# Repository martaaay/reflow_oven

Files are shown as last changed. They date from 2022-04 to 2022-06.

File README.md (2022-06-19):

# Reflow Oven

Based on EZ Make Oven by Adafruit.

* Sparkfun MCP9600 with QWIIC connectors
* Hamilton Beach Countertop Toaster Oven & Pizza Maker 31401
* Adafruit Metro M4 feat. Microchip ATSAMD51
* Adafruit "Music Maker" MP3 Shield for Arduino w/3W Stereo Amp
* Speaker - 40mm Diameter - 4 Ohm 3 Watt
* 2.8" TFT Touch Shield for Arduino w/Capacitive Touch
* SSR-25DA DC->AC. https://www.amazon.com/gp/product/B08GPJ1V2J 

The toaster oven should disassembled and insulated. This is a good guide:
https://www.whizoo.com/reflowoven
Don't skimp on the reflective tape on the door! Be careful about wiring as 110V is involved.

Pry the knobs off the front panel. I suggest using a regular screwdriver from the back and twisting
to pry it up. Once off, unscrew all the controls so you're left with the bent sheetmetal. Print
the front panel in a higher temp plastic (though it really wont have to handle much heat). I printed
in Nylon. ABS should work too. Using a dremal + grinder (or something similar) carefully cutout a rectangle
to fit the front panel. Insert threaded inserts into the screw holes in the front panel. These work great:
https://www.amazon.com/gp/product/B07LBRR2ZB/
And screw it into place in the sheet metal front panel. The rest is just wiring, testing, and re-assembling.

Future work:
* Consider swapping to Arduino code over Circuit Python. Circuit Python is very slow, especially for playing
sounds.

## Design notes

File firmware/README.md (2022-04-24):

# EZ Make Oven

The EZ Make Oven is an easy to build reflow oven utilizing a PyPortal as
the controller. It also uses the Adafruit MCP9600 thermocouple amplifier, a thermocouple and the IoT Power Relay from Digital Loggers.

A standard, non-digital toaster oven is needed for this project, which can be purchased online or at your nearest appliance store. It should be small (4 slice capacity), at least 1100 watts and a maximum temperature of 450F / 230C or better.

Follow the Adafruit learn guide here: https://learn.adafruit.com/ez-make-oven

Run **codecalibrate.py** first to determine calibration settings for your toaster oven. You will need to re-run this if you switch toaster ovens or update the EZ Make Oven software. The calibration values displayed will need to be manually entered into the **config.json file**. This file also contains the I2C address of your MCP9600 breakout (in decimal) and the name of the solder profile to use. Available solder profiles can be found in the profiles folder. You will need to rename this file to **code.py** in order to run it.

**code.py** is the EZ Make Oven code that will run the program when the board boots up.

Adafruit invests time and resources providing this open source code,
please support Adafruit and open-source hardware by purchasing
products from [Adafruit](https://www.adafruit.com)!
 
MIT license, code and guide written by Dan Cogliano

All text above, and the splash screen below must be included in any redistribution

-----------------------
If you are looking to make changes/additions, please use the GitHub Issues and Pull Request mechanisms.

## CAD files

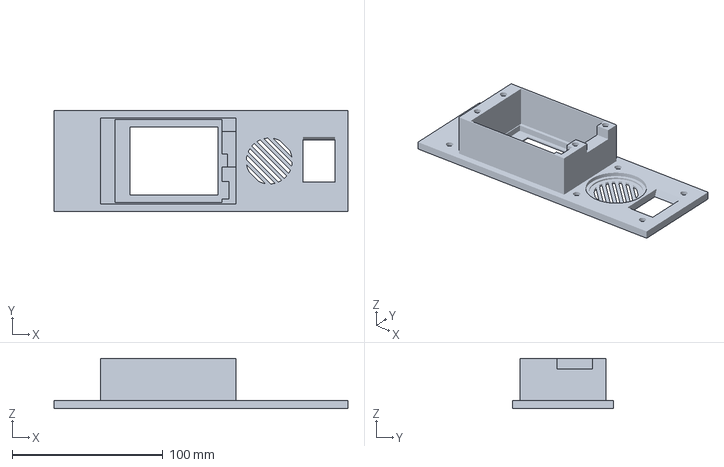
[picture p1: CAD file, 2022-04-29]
mechanical/UMS5_Reflow Oven - Front Panel.3mf
195.3 x 67.0 x 33.4 mm

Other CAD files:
mechanical/Reflow Oven - Front Panel.3mf

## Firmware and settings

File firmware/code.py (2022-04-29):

# SPDX-FileCopyrightText: 2019 Dan Cogliano for Adafruit Industries
#
# SPDX-License-Identifier: MIT

import time
import json
import array
import math
import gc
import board
import busio
import audioio
import audiocore
import displayio
import digitalio
from adafruit_bitmap_font import bitmap_font
from adafruit_display_text import bitmap_label as label
from adafruit_display_shapes.circle import Circle
from adafruit_button import Button
from adafruit_mcp9600 import MCP9600
import adafruit_ili9341
import adafruit_focaltouch
import adafruit_vs1053
from adafruit_display_shapes.roundrect import RoundRect

TITLE = "EZ Make Oven Controller!"
VERSION = "1.3.2"

print(TITLE, "version ", VERSION)
time.sleep(2)

displayio.release_displays()

spi = board.SPI()

tft_cs = board.D10
tft_dc = board.D9

AUDIO_MP3CS = board.D7  # Pin connected to VS1053 CS line.
AUDIO_DREQ = board.D3  # Pin connected to VS1053 DREQ line.
AUDIO_XDCS = board.D6  # Pin connected to VS1053 D/C line.
vs1053 = adafruit_vs1053.VS1053(spi, AUDIO_MP3CS, AUDIO_XDCS, AUDIO_DREQ)
vs1053.set_volume(0, 0)

REFLOW_CONTROL_PIN = board.D13
POWER_SWITCH_STATUS_PIN = board.D4 # Has pull up from display pcb

power_switch_status = digitalio.DigitalInOut(POWER_SWITCH_STATUS_PIN)
power_switch_status.direction = digitalio.Direction.INPUT

i2c = busio.I2C(board.SCL, board.SDA, frequency=100000)
ft = adafruit_focaltouch.Adafruit_FocalTouch(i2c, debug=False)

WIDTH = 240
HEIGHT = 320

display_bus = displayio.FourWire(spi, command=tft_dc, chip_select=tft_cs)
display = adafruit_ili9341.ILI9341(display_bus, width=WIDTH, height=HEIGHT, rotation=90)


# Make the display context
display_group = displayio.Group()
display.show(display_group)

PROFILE_SIZE = 2  # plot thickness
GRID_SIZE = 2
GRID_STYLE = 3
TEMP_SIZE = 2
AXIS_SIZE = 2

BLACK = 0x0
BLUE = 0x2020FF
GREEN = 0x00FF55
RED = 0xFF0000
YELLOW = 0xFFFF00


palette = displayio.Palette(5)
palette[0] = BLACK
palette[1] = GREEN
palette[2] = BLUE
palette[3] = RED
palette[4] = YELLOW

palette.make_transparent(0)

BACKGROUND_COLOR = 0
PROFILE_COLOR = 1
GRID_COLOR = 2
TEMP_COLOR = 3
AXIS_COLOR = 2

GXSTART = 0
GYSTART = 160
GWIDTH = WIDTH - GXSTART
GHEIGHT = HEIGHT - GYSTART
plot = displayio.Bitmap(GWIDTH, GHEIGHT, 4)

display_group.append(
    displayio.TileGrid(plot, pixel_shader=palette, x=GXSTART, y=GYSTART)
)



class Beep(object):
    def __init__(self):
        pass

    # pylint: disable=protected-access
    def play(self, duration=0.1):
        vs1053.sine_test(0x66, duration)

    def stop(self):
        pass
        #if self._speaker_enable.value:
        #    self.duration = 0
        #    self.audio.stop()
        #    self._speaker_enable.value = False

    def refresh(self):
        pass
        #if time.monotonic() - self.start >= self.duration:
        #    self.stop()


class ReflowOvenControl(object):
    states = ("wait", "ready", "start", "preheat", "soak", "reflow", "cool")

    def __init__(self, pin):
        global i2c
        self.oven = digitalio.DigitalInOut(pin)
        self.oven.direction = digitalio.Direction.OUTPUT
        with open("/config.json", mode="r") as fpr:
            self.config = json.load(fpr)
            fpr.close()
        self.sensor_status = False
        with open("/profiles/" + self.config["profile"] + ".json", mode="r") as fpr:
            self.sprofile = json.load(fpr)
            fpr.close()
        try:
            self.sensor = MCP9600(i2c, 0x60, "K")
            self.ontemp = self.sensor.temperature
            self.offtemp = self.ontemp
            self.sensor_status = True
        except ValueError:
            print("temperature sensor not available")
        self.control = False
        self.reset()
        self.beep = Beep()
        self.set_state("ready")
        if self.sensor_status:
            if self.sensor.temperature >= 50:
                self.last_state = "wait"
                self.set_state("wait")

    def reset(self):
        self.ontime = 0
        self.offtime = 0
        self.enable(False)
        self.reflow_start = 0

    def get_profile_temp(self, seconds):
        x1 = self.sprofile["profile"][0][0]
        y1 = self.sprofile["profile"][0][1]
        for point in self.sprofile["profile"]:
            x2 = point[0]
            y2 = point[1]
            if x1 <= seconds < x2:
                temp = y1 + (y2 - y1) * (seconds - x1) // (x2 - x1)
                return temp
            x1 = x2
            y1 = y2
        return 0

    def set_state(self, state):
        self.state = state
        self.check_state()
        self.last_state = state

    # pylint: disable=too-many-branches, too-many-statements
    def check_state(self):
        try:
            temp = self.sensor.temperature
        except AttributeError:
            temp = 32  # sensor not available, use 32 for testing
            self.sensor_status = False
            # set_message("Temperature sensor missing")
        self.beep.refresh()
        if self.state == "wait":
            self.enable(False)
            if self.state != self.last_state:
                # change in status, time for a beep!
                self.beep.play(0.1)
            if temp < 35:
                self.set_state("ready")
                oven.reset()
                draw_profile(sgraph, oven.sprofile)
                timer_data.text = format_time(0)

        if self.state == "ready":
            self.enable(False)
        if self.state == "start" and temp >= 50:
            self.set_state("preheat")
        if self.state == "start":
            set_message("Starting")
            self.enable(True)
        if self.state == "preheat" and temp >= self.sprofile["stages"]["soak"][1]:
            self.set_state("soak")
        if self.state == "preheat":
            set_message("Preheat")
        if self.state == "soak" and temp >= self.sprofile["stages"]["reflow"][1]:
            self.set_state("reflow")
        if self.state == "soak":
            set_message("Soak")
        if (
            self.state == "reflow"
            and temp >= self.sprofile["stages"]["cool"][1]
            and self.reflow_start > 0
            and (
                time.monotonic() - self.reflow_start
                >= self.sprofile["stages"]["cool"][0]
                - self.sprofile["stages"]["reflow"][0]
            )
        ):
            self.set_state("cool")
            self.beep.play(5)
        if self.state == "reflow":
            set_message("Reflow")
            if self.last_state != "reflow":
                self.reflow_start = time.monotonic()
        if self.state == "cool":
            self.enable(False)
            set_message("Cool Down", "Open Door")

        if self.state in ("start", "preheat", "soak", "reflow"):
            if self.state != self.last_state:
                # change in status, time for a beep!
                self.beep.play(0.1)
            # oven temp control here
            # check range of calibration to catch any humps in the graph
            checktime = 0
            checktimemax = self.config["calibrate_seconds"]
            checkoven = False
            if not self.control:
                checktimemax = max(
                    0,
                    self.config["calibrate_seconds"]
                    - (time.monotonic() - self.offtime),
                )
            while checktime <= checktimemax:
                check_temp = self.get_profile_temp(int(timediff + checktime))
                if (
                    temp + self.config["calibrate_temp"] * checktime / checktimemax
                    < check_temp
                ):
                    checkoven = True
                    break
                checktime += 5
            if not checkoven:
                # hold oven temperature
                if (
                    self.state in ("start", "preheat", "soak")
                    and self.offtemp > self.sensor.temperature
                ):
                    checkoven = True
            self.enable(checkoven)

    # turn oven on or off
    def enable(self, enable):
        try:
            self.oven.value = enable
            self.control = enable
            if enable:
                self.offtime = 0
                self.ontime = time.monotonic()
                self.ontemp = self.sensor.temperature
                print("oven on")
            else:
                self.offtime = time.monotonic()
                self.ontime = 0
                self.offtemp = self.sensor.temperature
                print("oven off")
        except AttributeError:
            # bad sensor
            pass


class Graph(object):
    def __init__(self):
        self.xmin = 0
        self.xmax = 720  # graph up to 12 minutes
        self.ymin = 0
        self.ymax = 240
        self.xstart = 0
        self.ystart = 0
        self.width = GWIDTH
        self.height = GHEIGHT

    # pylint: disable=too-many-branches
    def draw_line(self, x1, y1, x2, y2, size=PROFILE_SIZE, color=1, style=1):
        # print("draw_line:", x1, y1, x2, y2)
        # convert graph coords to screen coords
        x1p = self.xstart + self.width * (x1 - self.xmin) // (self.xmax - self.xmin)
        y1p = self.ystart + int(
            self.height * (y1 - self.ymin) / (self.ymax - self.ymin)
        )
        x2p = self.xstart + self.width * (x2 - self.xmin) // (self.xmax - self.xmin)
        y2p = self.ystart + int(
            self.height * (y2 - self.ymin) / (self.ymax - self.ymin)
        )
        # print("screen coords:", x1p, y1p, x2p, y2p)

        if (max(x1p, x2p) - min(x1p, x2p)) > (max(y1p, y2p) - min(y1p, y2p)):
            for xx in range(min(x1p, x2p), max(x1p, x2p)):
                if x2p != x1p:
                    yy = y1p + (y2p - y1p) * (xx - x1p) // (x2p - x1p)
                    if style == 2:
                        if xx % 2 == 0:
                            self.draw_point(xx, yy, size, color)
                    elif style == 3:
                        if xx % 8 == 0:
                            self.draw_point(xx, yy, size, color)
                    elif style == 4:
                        if xx % 12 == 0:
                            self.draw_point(xx, yy, size, color)
                    else:
                        self.draw_point(xx, yy, size, color)
        else:
            for yy in range(min(y1p, y2p), max(y1p, y2p)):
                if y2p != y1p:
                    xx = x1p + (x2p - x1p) * (yy - y1p) // (y2p - y1p)
                    if style == 2:
                        if yy % 2 == 0:
                            self.draw_point(xx, yy, size, color)
                    elif style == 3:
                        if yy % 8 == 0:
                            self.draw_point(xx, yy, size, color)
                    elif style == 4:
                        if yy % 12 == 0:
                            self.draw_point(xx, yy, size, color)
                    else:
                        self.draw_point(xx, yy, size, color)

    def draw_graph_point(self, x, y, size=PROFILE_SIZE, color=1):
        """ draw point using graph coordinates """

        # wrap around graph point when x goes out of bounds
        x = (x - self.xmin) % (self.xmax - self.xmin) + self.xmin
        xx = self.xstart + self.width * (x - self.xmin) // (self.xmax - self.xmin)
        yy = self.ystart + int(self.height * (y - self.ymin) / (self.ymax - self.ymin))
        print("graph point:", x, y, xx, yy)
        self.draw_point(xx, max(0 + size, yy), size, color)

    def draw_point(self, x, y, size=PROFILE_SIZE, color=1):
        """Draw data point on to the plot bitmap at (x,y)."""
        if y is None:
            return
        offset = size // 2
        for xx in range(x - offset, x + offset + 1):
            if xx in range(self.xstart, self.xstart + self.width):
                for yy in range(y - offset, y + offset + 1):
                    if yy in range(self.ystart, self.ystart + self.height):
                        try:
                            yy = GHEIGHT - yy
                            plot[xx, yy] = color
                        except IndexError:
                            pass


def draw_profile(graph, profile):
    """Update the display with current info."""
    for i in range(GWIDTH * GHEIGHT):
        plot[i] = 0

    # draw stage lines
    # preheat
    graph.draw_line(
        profile["stages"]["preheat"][0],
        profile["temp_range"][0],
        profile["stages"]["preheat"][0],
        profile["temp_range"][1] * 1.1,
        GRID_SIZE,
        GRID_COLOR,
        GRID_STYLE,
    )
    graph.draw_line(
        profile["time_range"][0],
        profile["stages"]["preheat"][1],
        profile["time_range"][1],
        profile["stages"]["preheat"][1],
        GRID_SIZE,
        GRID_COLOR,
        GRID_STYLE,
    )
    # soak
    graph.draw_line(
        profile["stages"]["soak"][0],
        profile["temp_range"][0],
        profile["stages"]["soak"][0],
        profile["temp_range"][1] * 1.1,
        GRID_SIZE,
        GRID_COLOR,
        GRID_STYLE,
    )
    graph.draw_line(
        profile["time_range"][0],
        profile["stages"]["soak"][1],
        profile["time_range"][1],
        profile["stages"]["soak"][1],
        GRID_SIZE,
        GRID_COLOR,
        GRID_STYLE,
    )
    # reflow
    graph.draw_line(
        profile["stages"]["reflow"][0],
        profile["temp_range"][0],
        profile["stages"]["reflow"][0],
        profile["temp_range"][1] * 1.1,
        GRID_SIZE,
        GRID_COLOR,
        GRID_STYLE,
    )
    graph.draw_line(
        profile["time_range"][0],
        profile["stages"]["reflow"][1],
        profile["time_range"][1],
        profile["stages"]["reflow"][1],
        GRID_SIZE,
        GRID_COLOR,
        GRID_STYLE,
    )
    # cool
    graph.draw_line(
        profile["stages"]["cool"][0],
        profile["temp_range"][0],
        profile["stages"]["cool"][0],
        profile["temp_range"][1] * 1.1,
        GRID_SIZE,
        GRID_COLOR,
        GRID_STYLE,
    )
    graph.draw_line(
        profile["time_range"][0],
        profile["stages"]["cool"][1],
        profile["time_range"][1],
        profile["stages"]["cool"][1],
        GRID_SIZE,
        GRID_COLOR,
        GRID_STYLE,
    )

    # draw labels
    x = profile["time_range"][0]
    y = profile["stages"]["reflow"][1]
    xp = int(GXSTART + graph.width * (x - graph.xmin) // (graph.xmax - graph.xmin))
    yp = int(GHEIGHT * (y - graph.ymin) // (graph.ymax - graph.ymin))

    label_reflow.x = xp + 10
    label_reflow.y = HEIGHT - yp
    label_reflow.text = str(profile["stages"]["reflow"][1])
    print("reflow temp:", str(profile["stages"]["reflow"][1]))
    print("graph point: ", x, y, "->", xp, yp)

    x = profile["stages"]["reflow"][0]
    y = profile["stages"]["reflow"][1]

    # draw time line (horizontal)
    graph.draw_line(
        graph.xmin, graph.ymin + 1, graph.xmax, graph.ymin + 1, AXIS_SIZE, AXIS_COLOR, 1
    )
    graph.draw_line(
        graph.xmin, graph.ymax, graph.xmax, graph.ymax, AXIS_SIZE, AXIS_COLOR, 1
    )
    # draw time ticks
    tick = graph.xmin
    while tick < (graph.xmax - graph.xmin):
        graph.draw_line(
            tick, graph.ymin, tick, graph.ymin + 10, AXIS_SIZE, AXIS_COLOR, 1
        )
        graph.draw_line(
            tick,
            graph.ymax,
            tick,
            graph.ymax - 10 - AXIS_SIZE,
            AXIS_SIZE,
            AXIS_COLOR,
            1,
        )
        tick += 60

    # draw temperature line (vertical)
    graph.draw_line(
        graph.xmin, graph.ymin, graph.xmin, graph.ymax, AXIS_SIZE, AXIS_COLOR, 1
    )
    graph.draw_line(
        graph.xmax - AXIS_SIZE + 1,
        graph.ymin,
        graph.xmax - AXIS_SIZE + 1,
        graph.ymax,
        AXIS_SIZE,
        AXIS_COLOR,
        1,
    )
    # draw temperature ticks
    tick = graph.ymin
    while tick < (graph.ymax - graph.ymin) * 1.1:
        graph.draw_line(
            graph.xmin, tick, graph.xmin + 10, tick, AXIS_SIZE, AXIS_COLOR, 1
        )
        graph.draw_line(
            graph.xmax,
            tick,
            graph.xmax - 10 - AXIS_SIZE,
            tick,
            AXIS_SIZE,
            AXIS_COLOR,
            1,
        )
        tick += 50

    # draw profile
    x1 = profile["profile"][0][0]
    y1 = profile["profile"][0][1]
    for point in profile["profile"]:
        x2 = point[0]
        y2 = point[1]
        graph.draw_line(x1, y1, x2, y2, PROFILE_SIZE, PROFILE_COLOR, 1)
        # print(point)
        x1 = x2
        y1 = y2


def format_time(seconds):
    minutes = seconds // 60
    seconds = int(seconds) % 60
    return "{:02d}:{:02d}".format(minutes, seconds, width=2)

timediff = 0
oven = ReflowOvenControl(REFLOW_CONTROL_PIN)
print("melting point: ", oven.sprofile["melting_point"])
font1 = bitmap_font.load_font("/fonts/OpenSans-9.bdf")

font2 = bitmap_font.load_font("/fonts/OpenSans-12.bdf")

font3 = bitmap_font.load_font("/fonts/OpenSans-16.bdf")

label_reflow = label.Label(font1, text="", color=0xFFFFFF, line_spacing=0)
label_reflow.x = 0
label_reflow.y = -20
display_group.append(label_reflow)
#title_label = label.Label(font3, text=TITLE)
#title_label.x = 5
#title_label.y = 14
#display_group.append(title_label)
profile_label = label.Label(font1, text="Profile:", color=0xAAAAAA)
profile_label.x = 5
profile_label.y = 10
display_group.append(profile_label)
profile_data = label.Label(font1, text=oven.sprofile["title"])
profile_data.x = 10
profile_data.y = 30-4
display_group.append(profile_data)
alloy_label = label.Label(font1, text="Alloy:", color=0xAAAAAA)
alloy_label.x = 5
alloy_label.y = 80-30-4
display_group.append(alloy_label)
alloy_data = label.Label(font1, text=str(oven.sprofile["alloy"]))
alloy_data.x = 10
alloy_data.y = 100-30-8
display_group.append(alloy_data)
timer_label = label.Label(font1, text="Time:", color=0xAAAAAA)
timer_label.x = 5
timer_label.y = 120-30-8
display_group.append(timer_label)
timer_data = label.Label(font3, text=format_time(timediff))
timer_data.x = 10
timer_data.y = 140-30-12
display_group.append(timer_data)
temp_label = label.Label(font1, text="Temp(C):", color=0xAAAAAA)
temp_label.x = 5
temp_label.y = 160-30-12
display_group.append(temp_label)
temp_data = label.Label(font3, text="--")
temp_data.x = 10
temp_data.y = 180-30-16
display_group.append(temp_data)
circle = Circle(308, 12, 8, fill=0)
display_group.append(circle)
message1 = label.Label(font2, text="Wait")
message1.x = 90
message1.y = 10
display_group.append(message1)
message2 = label.Label(font2, text="")
message2.x = 90
message2.y = 30
display_group.append(message2)

sgraph = Graph()

# sgraph.xstart = 100
# sgraph.ystart = 4
sgraph.xstart = 0
sgraph.ystart = 0
# sgraph.width = WIDTH - sgraph.xstart - 4  # 216 for standard PyPortal
# sgraph.height = HEIGHT - 80  # 160 for standard PyPortal
sgraph.width = GWIDTH  # 216 for standard PyPortal
sgraph.height = GHEIGHT  # 160 for standard PyPortal
sgraph.xmin = oven.sprofile["time_range"][0]
sgraph.xmax = oven.sprofile["time_range"][1]
sgraph.ymin = oven.sprofile["temp_range"][0]
sgraph.ymax = oven.sprofile["temp_range"][1] * 1.1
print("x range:", sgraph.xmin, sgraph.xmax)
print("y range:", sgraph.ymin, sgraph.ymax)
draw_profile(sgraph, oven.sprofile)

#if oven.sensor_status:
button = Button(
    x=WIDTH-80, y=GYSTART-50, width=80, height=40, label="Disabled", label_font=font2, style=Button.ROUNDRECT
)
button._label.y -= 4;
display_group.append(button)

def set_message(line1, line2=""):
    global message1, message2
    message1.text = line1
    message2.text = line2
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

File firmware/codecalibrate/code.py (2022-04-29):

# SPDX-FileCopyrightText: 2019 Dan Cogliano for Adafruit Industries
#
# SPDX-License-Identifier: MIT

import time
import sys
import board
import busio
import digitalio
from adafruit_mcp9600 import MCP9600

SENSOR_ADDR = 0X60

i2c = busio.I2C(board.SCL, board.SDA,frequency=200000)
try:
    sensor = MCP9600(i2c,SENSOR_ADDR,"K")
except ValueError as e:
    print(e)
    print("Unable to connect to the thermocouple sensor.")
    sys.exit(1)

REFLOW_CONTROL_PIN = board.D13
oven = digitalio.DigitalInOut(REFLOW_CONTROL_PIN)
oven.direction = digitalio.Direction.OUTPUT

def oven_control(enable=False):
    #board.D4
    oven.value = enable

check_temp = 100
print("This program will determine calibration settings ")
print("for your oven to use with the EZ Make Oven.\n\n")
for i in range(10):
    print("Calibration will start in %d seconds..." % (10-i))
    time.sleep(1)
print("Starting...")
print("Calibrating oven temperature to %d C" % check_temp)
finish = False
oven_control(True)
maxloop=300
counter = 0
while not finish:
    time.sleep(1)
    counter += 1
    current_temp = sensor.temperature
    print("%.02f C" % current_temp)
    if current_temp >= check_temp:
        finish = True
        oven_control(False)
    if counter >= maxloop:
        raise Exception("Oven not working or bad sensor")

print("checking oven lag time and temperature")
finish = False
start_time = time.monotonic()
start_temp = sensor.temperature
last_temp = start_temp

while not finish:
    time.sleep(1)
    current_temp = sensor.temperature
    print(current_temp)
    if current_temp <= last_temp:
        finish = True
    last_temp = current_temp

lag_temp = last_temp - check_temp
lag_time = int(time.monotonic() - start_time)

print("** Calibration Results **")
print("Modify config.json with these values for your oven:")
print("calibrate_temp:", lag_temp)
print("calibrate_seconds:",lag_time)

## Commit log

2022-04-25 More bringup
    [Reflow Oven - Front Panel.3mf]
2022-04-29 Oven working, but ramp speed too slow
    [Reflow Oven - Front Panel.3mf, UMS5_Reflow Oven - Front Panel.3mf]
